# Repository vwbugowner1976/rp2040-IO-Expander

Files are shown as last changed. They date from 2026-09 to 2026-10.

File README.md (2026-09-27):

# RP2040-Zero BLE I/O Rev.W

Fresh mechanical-master revision for the RP2040-Zero BLE adapter concept.

- 18 × 23.5 mm
- RP2040-Zero THT/castellation geometry from the supplied master footprint
- USB-C + BOOT + RESET on F.Cu side
- 24P FFC on B.Cu side
- MDBT50Q-1MV2 is a separate core board
- FFC 1–20 = GPIO0–15, GPIO26–29
- FFC 21 = 3V3
- FFC 22 = GND
- FFC 23 = VSYS
- FFC 24 = USB_VBUS

This is the clean mechanical/electrical-interface baseline. PCB routing is intentionally kept separate from the mechanical master so it does not silently corrupt the reference geometry.

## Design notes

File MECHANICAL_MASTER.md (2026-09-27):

# RP2040-Zero BLE I/O — Rev.W

## Mechanical master
The 23 exposed RP2040-Zero THT connection positions are derived from the supplied third-party footprint:
`is-watering/isw-kbd-lib/footprints/isw-kbd.pretty/RP2040-Zero-THT.kicad_mod`

This is used as the **mechanical/pad master**, not claimed as an official Waveshare PCB source.

Board outline: **18.0 × 23.5 mm**.

The pad geometry preserves the characteristic RP2040-Zero THT/castellation arrangement:
- right: GPIO0–8
- top: GPIO9–13
- left: GPIO14, GPIO15, GPIO26–29, 3V3, GND, VSYS
- 0.85 mm drill
- 0.50 mm inward drill offset relative to the pad center, reproducing the footprint's inner-hole/castellation geometry

## I/O architecture
- RP2040, flash, regulator and LED are intentionally removed.
- USB-C remains on the original-side area.
- BOOT and RESET remain on the same surface.
- 24P Hirose FH34SRJ-24S-0.5SH(50) footprint is on B.Cu; the mating BLE CORE uses the matching 24P host connector.
- FFC is inside the 18 × 23.5 mm outline.
- Separate BLE core target: Raytac MDBT50Q-1MV2.

## FFC mapping
See `PINMAP.csv`.

## Important validation note
KiCad PCBNew/DRC is not installed in the generation environment, so this revision has been syntactically checked and coordinate-checked but has **not** been claimed as KiCad DRC/3D-verified.

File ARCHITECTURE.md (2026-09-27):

# Rev.J Architecture Freeze

```text
                 RP2040-Zero footprint
                         │
                    ┌────┴────┐
 USB-C ── ESD ─────▶│  IO PCB │◀── 6P Trackball
                    │  Power  │
                    └────┬────┘
                         │ 24P FFC
             20 GPIO + USB + debug + TB + GND
                         │
                    ┌────┴────┐
                    │ BLE Core│
                    │ MDBT50Q │── extra GPIO expansion
                    └─────────┘
```

### Design rule
The 20 legacy GPIOs are never multiplexed. They remain 1:1 from the original RP2040-Zero connector to the nRF52840. Added peripherals use dedicated Core GPIOs.

### Trackball
The IO-board 6P connector is carried on dedicated FFC lines TB1..TB6 and therefore does not consume any of the 20 legacy keyboard GPIOs. This is the key architectural change from Rev.I.

### FFC
24P is the final host interconnect. It carries the 20 legacy GPIOs plus 3V3, GND, VSYS and USB_VBUS. TB1..TB6 remain dedicated BLE-core expansion lines and are not part of the RP2040-Zero host FFC.

## Rev.Q mechanical correction
- IO board: 18.0 x 23.5 mm.
- RP2040-Zero 23 edge pads are mapped by the actual physical edge layout, not by the schematic P1 numbering order: left edge = 5V/VSYS, GND, 3V3, GPIO29, GPIO28, GPIO27, GPIO26, GPIO15, GPIO14; bottom edge = GPIO13..GPIO8; right edge = GPIO0..GPIO7.
- Pad centers follow the published 18.00 x 23.50 mm drawing: side X=1.38 / 16.62, first side Y=1.59, 2.54 mm pitch; bottom Y=22.12 with X=1.38..14.08 at 2.54 mm pitch.
- THT hole 0.80 mm, pad 1.60 mm.
- FFC changed to Hirose FH34SRJ-24S-0.5SH(50), 24 positions, 14.0 x 3.8 mm, placed on F.Cu on the USB-connector side.
- FFC pins 1-20 = GPIO0..GPIO15/GPIO26..GPIO29; 21=3V3, 22=GND, 23=VSYS, 24=USB_VBUS.

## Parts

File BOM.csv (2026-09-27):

Designator | Part | LCSC | Role
U1 | MDBT50Q-1MV2 | C5118826 | BLE Core
J1 | FH34SRJ-40S-0.5SH(50) | C506798 | IO<->Core 40P FFC
J2 | TYPE-C-31-M-12 | C165948 | USB-C
D1 | USBLC6-2SC6 | C7519 | USB ESD
U2 | TPS61099DRVR | C2842395 | VSYS to 3V3 converter
U3 | TPS7A2033PDBVR |  | USB VBUS to 3V3 LDO
U4 | TPS2116DRLR |  | 3V3 power mux
L1 | 2.2uH shielded |  | TPS61099 inductor
R1 | 576k 1% |  | TPS61099 FB upper
R2 | 249k 1% |  | TPS61099 FB lower
R3 | 100k 1% |  | TPS2116 PR1 upper
R4 | 47k 1% |  | TPS2116 PR1 lower
CIN | 10uF |  | power input bulk
COUT | 10uF |  | power output bulk
CUSB | 1uF |  | TPS7A20 input/output per datasheet
C3V3 | 10uF |  | 3V3 local bulk

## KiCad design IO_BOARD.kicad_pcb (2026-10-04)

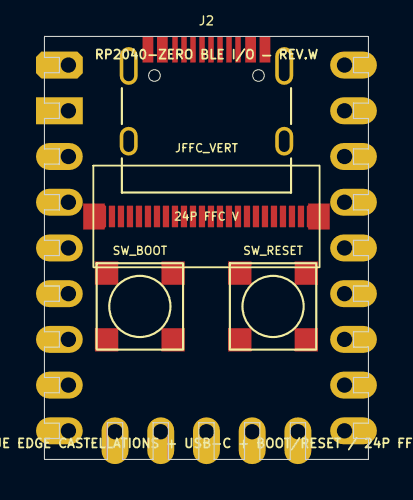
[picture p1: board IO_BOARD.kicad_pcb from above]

Board: 4 copper layers, 18.0 x 23.5 mm, 6 parts (1 on the bottom side), 28 nets, no tracks yet.

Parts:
J2: TYPE-C-31-M-12
JFFC: FH34SRJ-24S-0.5SH(50)
JFFC_VERT: FH40-24S-0.5SV
JLEG: RP2040-Zero-THT; RP2040-Zero-THT-Castellation-Master
SW_BOOT: TS-1187A-B-A-B / C318884; SW-SMD_4P-L5.1-W5.1-P3.70-LS6.5-TL_H1.5
SW_RESET: TS-1187A-B-A-B / C318884; SW-SMD_4P-L5.1-W5.1-P3.70-LS6.5-TL_H1.5

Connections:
3V3: JFFC.21, JFFC_VERT.21, JLEG.30
BOOT: SW_BOOT.2, SW_BOOT.3
GND: J2.A1, J2.A12, J2.B1, J2.B12, JFFC.22, JFFC_VERT.22, JLEG.31, SW_BOOT.1, SW_BOOT.4, SW_RESET.1, SW_RESET.4
GPIO0: JFFC.1, JFFC_VERT.1, JLEG.0
GPIO1: JFFC.2, JFFC_VERT.2, JLEG.1
GPIO2: JFFC.3, JFFC_VERT.3, JLEG.2
GPIO3: JFFC.4, JFFC_VERT.4, JLEG.3
GPIO4: JFFC.5, JFFC_VERT.5, JLEG.4
GPIO5: JFFC.6, JFFC_VERT.6, JLEG.5
GPIO6: JFFC.7, JFFC_VERT.7, JLEG.6
GPIO7: JFFC.8, JFFC_VERT.8, JLEG.7
GPIO8: JFFC.9, JFFC_VERT.9, JLEG.8
GPIO9: JFFC.10, JFFC_VERT.10, JLEG.9
GPIO10: JFFC.11, JFFC_VERT.11, JLEG.10
GPIO11: JFFC.12, JFFC_VERT.12, JLEG.11
GPIO12: JFFC.13, JFFC_VERT.13, JLEG.12
GPIO13: JFFC.14, JFFC_VERT.14, JLEG.13
GPIO14: JFFC.15, JFFC_VERT.15, JLEG.14
GPIO15: JFFC.16, JFFC_VERT.16, JLEG.15
GPIO26: JFFC.17, JFFC_VERT.17, JLEG.26
GPIO27: JFFC.18, JFFC_VERT.18, JLEG.27
GPIO28: JFFC.19, JFFC_VERT.19, JLEG.28
GPIO29: JFFC.20, JFFC_VERT.20, JLEG.29
RESET: SW_RESET.2, SW_RESET.3
USB_D+: J2.A6, J2.B6
USB_D-: J2.A7, J2.B7
USB_VBUS: J2.A4, J2.A9, J2.B4, J2.B9, JFFC.24, JFFC_VERT.24
VSYS: JFFC.23, JFFC_VERT.23, JLEG.32

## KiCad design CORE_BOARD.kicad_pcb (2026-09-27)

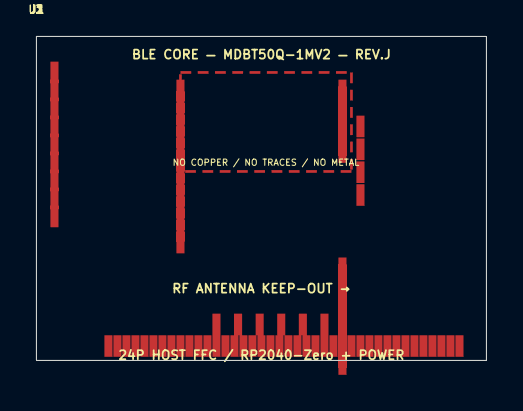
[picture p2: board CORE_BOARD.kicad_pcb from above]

Board: 4 copper layers, 25.0 x 18.0 mm, 4 parts (0 on the bottom side), 24 nets, no tracks yet.

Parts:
J1: FH34SRJ-24S-0.5SH(50)
J2: SWD-4P
J3: CORE-EXPANSION
U1: MDBT50Q-1MV2

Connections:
3V3: J1.21, J2.1
GND: J1.22, J1.37, J1.38, J1.39, J1.40, J2.4, U1.1, U1.2, U1.15, U1.55
GPIO0: J1.1, U1.9
GPIO1: J1.2, U1.20
GPIO2: J1.3, U1.21
GPIO3: J1.4, U1.22
GPIO4: J1.5, U1.23
GPIO5: J1.6, U1.24
GPIO14: J1.15, U1.41
GPIO15: J1.16, U1.42
GPIO26: J1.17, U1.44
GPIO27: J1.18, U1.43
GPIO28: J1.19, U1.46
GPIO29: J1.20, U1.45
NC: U1.3, U1.4, U1.5, U1.6, U1.7, U1.8, U1.10, U1.11, U1.12, U1.13, U1.14, U1.17, U1.18, U1.19, U1.47, U1.48, U1.49, U1.50, U1.52, U1.54
STATUS_LED: J1.28, U1.16
SWDCLK: J1.30, J2.3, U1.53
SWDIO: J1.29, J2.2, U1.51
TB1: J1.31, U1.56
TB2: J1.32, U1.57
TB3: J1.33, U1.58
TB4: J1.34, U1.59
TB5: J1.35, U1.60
TB6: J1.36, U1.61

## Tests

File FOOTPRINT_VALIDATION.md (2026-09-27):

# RP2040-Zero mechanical interface validation — Rev.J

The IO board uses an 18.0 x 23.5 mm board outline and a 23-pad edge interface matching the Waveshare RP2040-Zero pin layout.

Reference checks:
- Waveshare RP2040-Zero official documentation: 23-pin edge header, GPIO0..15, GPIO26..29, 3V3, GND, VSYS.
- Published KiCad community footprint geometry: side pad centers at x=2.54/17.78 mm, 2.54 mm pitch; five bottom pads at x=5.08..15.24 mm; overall mechanical reference approximately 18 x 23.5 mm.

Important: the community footprint itself carries a warning that it may be incorrect. Therefore it is treated as a geometry cross-check only; the official Waveshare pinout/documentation is the authority for signal numbering.

Rev.J no longer uses the previous generic 0.45 x 1.2 mm placeholder pads. The interface pads are edge-style 2.60 x 1.60 mm side lands and 1.60 x 2.60 mm bottom lands, positioned at the published 2.54 mm pitch locations.

## Rev.J follow-up mechanical correction

- RP2040-Zero interface pads 1-23 are now plated through-hole pads for 0.9 mm drill / 1.8 mm finished pad, preserving the existing pad centers and nets so standard 2.54 mm console/pogo/through-hole access can be used.
- The 40P FH34SRJ connector is now oriented vertically. Its 0.5 mm-pitch contact row runs along the 23.5 mm board dimension, keeping the connector envelope within the 18.0 x 23.5 mm PCB outline.
- The 40P pin-to-net mapping is unchanged from PINMAP.csv.
- Final fabrication clearance still requires verification against the exact HRS mechanical drawing and the physical RP2040-Zero mating arrangement.

## Rev.M mechanical correction
- RP2040-Zero interface corrected to the physical perimeter arrangement: 9 pads per long side plus 5 pads on the USB-opposite end.
- All 23 interface pads remain plated through-holes, 0.9 mm drill / 1.8 mm pad, with original logical nets preserved.
- FFC footprint remains vertical and was moved inward so the modeled connector envelope is inside the 18 x 23.5 mm board outline.
- This is a layout correction; exact HRS mechanical drawing and final KiCad DRC still require verification before fabrication.

## Rev.M follow-up
- RP2040-Zero 23-pad perimeter geometry corrected to the documented physical arrangement: 9 pads per long side plus 5 pads on the USB-opposite end, 2.54 mm pitch.
- Added the missing TYPE-C-31-M-12 USB-C receptacle footprint at the top edge.
- Moved the 40P FH34SRJ connector to the B.Cu side and inside the 18 x 23.5 mm outline; the simplified envelope is 4 x 21 mm after rotation.
- Final HRS/HRO mechanical drawings and KiCad DRC are still required before fabrication.

## Rev.N mechanical correction
- RP2040-Zero 23-pad edge interface was corrected using the Waveshare pad numbering/order and the measured castellated-pad geometry: 9 pads on the right edge, 5 pads on the USB-opposite short edge, and 9 pads on the left edge.
- Through-hole conversion retains the original pad-edge offsets; finished drill centers are inset from the PCB edge rather than simply placing hole centers on the old SMD pad anchors.
- Con-through / pin-header compatibility: 0.8 mm finished drill, 2.6 x 1.6 mm side pads / 1.6 x 2.6 mm short-edge pads.
- FH34SRJ-24S-0.5SH(50) is centered at x=9.0 mm, y=11.75 mm and rotated 90 degrees. The connector envelope is modeled as 22.0 x 3.8 mm, giving 0.75 mm clearance at both ends along the 23.5 mm board dimension.
- 40-pin contact row remains 0.5 mm pitch and all 40 net assignments are unchanged.
- USB-C footprint remains present on the F.Cu side.
- This is a mechanical/pin-placement correction; full KiCad DRC and exact vendor 3D interference checking still require KiCad/vendor model verification.

## Rev.Q mechanical correction
- IO board: 18.0 x 23.5 mm.
- RP2040-Zero 23 edge pads are mapped by the actual physical edge layout, not by the schematic P1 numbering order: left edge = 5V/VSYS, GND, 3V3, GPIO29, GPIO28, GPIO27, GPIO26, GPIO15, GPIO14; bottom edge = GPIO13..GPIO8; right edge = GPIO0..GPIO7.
- Pad centers follow the published 18.00 x 23.50 mm drawing: side X=1.38 / 16.62, first side Y=1.59, 2.54 mm pitch; bottom Y=22.12 with X=1.38..14.08 at 2.54 mm pitch.
- THT hole 0.80 mm, pad 1.60 mm.
- FFC changed to Hirose FH34SRJ-24S-0.5SH(50), 24 positions, 14.0 x 3.8 mm, placed on F.Cu on the USB-connector side.
- FFC pins 1-20 = GPIO0..GPIO15/GPIO26..GPIO29; 21=3V3, 22=GND, 23=VSYS, 24=USB_VBUS.

## Rev.R checks
- Edge.Cuts: 18.0 x 23.5 mm.
- 23 RP2040-Zero THT drill centers all lie inside the outline.
- 24P FFC simplified envelope: X=2.0..16.0 mm, Y=5.1..8.9 mm; fully inside outline.
- No KiCad offset pad syntax is used.

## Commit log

2026-09-27 add
    add
    [BOM.csv, CORE_BOARD.kicad_pcb, IO_BOARD.kicad_pcb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]
2026-09-27 Finalize CORE host FFC as 24P
    [CORE_BOARD.kicad_pcb]
2026-09-27 Fix RP2040-Zero GPIO26-29 net assignments
    [IO_BOARD.kicad_pcb]
2026-09-27 Add 24P vertical FFC on front side
    [IO_BOARD.kicad_pcb]
2026-09-27 Use castellated SMD RP2040-Zero mechanical master
    [IO_BOARD.kicad_pcb]
2026-09-27 Restore exact RP2040-Zero THT castellated master geometry
    [IO_BOARD.kicad_pcb]
2026-09-27 Make RP2040-Zero edge holes true castellations
    [IO_BOARD.kicad_pcb]
2026-09-27 Align RP2040-Zero edge drills to board outline for castellations
    [IO_BOARD.kicad_pcb]
2026-09-27 Restore exact RP2040-Zero castellated pad geometry
    [IO_BOARD.kicad_pcb]
2026-09-27 Add true castellations and correct USB-C land pattern
    [IO_BOARD.kicad_pcb]
2026-09-27 Fix castellated Edge.Cuts continuity
    [IO_BOARD.kicad_pcb]
2026-10-04 Fix HRO TYPE-C-31-M-12 land pattern
    [IO_BOARD.kicad_pcb]
